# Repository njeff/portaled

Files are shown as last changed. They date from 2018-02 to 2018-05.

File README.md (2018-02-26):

# PortaLED

This is essentially a flashlight I designed because I wanted to use some free parts from TI. This uses the LM3410 driver to boost the voltage of the LiPo battery and drive the LEDs at a constant current. I have it setup to drive two 3W LEDs in series at approximately 630 mA (at max brightness). 

An ATTiny85 is used to control the whole system, and push button is used input.

This repository has the C firmware code and the KiCAD PCB design files. The PCB in the *const-led* folder has an additional battery gauge IC (MAX17043) for more accurate battery level tracking, and the one in *const-led-ez* doesn't. I only made the *ez* variant.

### Features
 - 8 brightness levels (maybe adjusted to be a linear/exponential ramp)
 - Battery level blink out (blinks out the volts, then tenth of a volt)
 - Low voltage/battery level cutoff
 - USB LiPo charging circuit

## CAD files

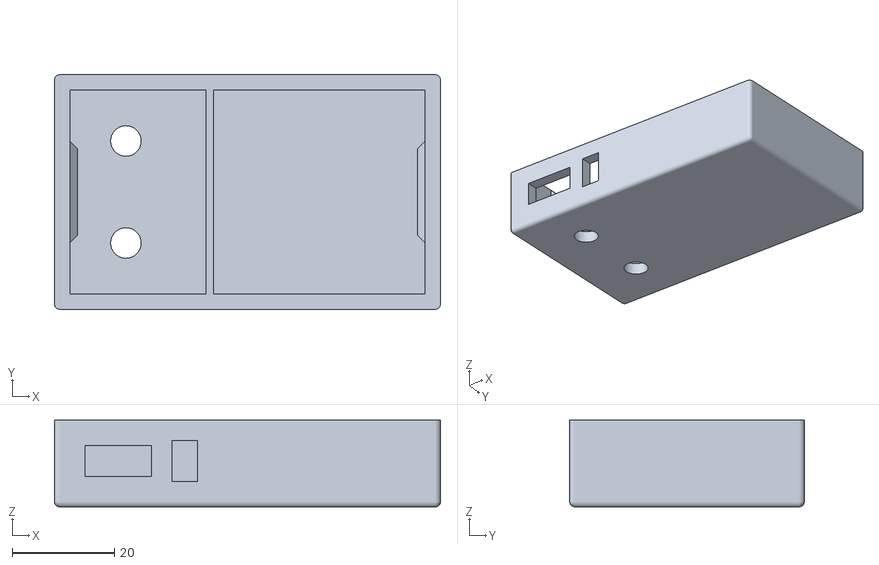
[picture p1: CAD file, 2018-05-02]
case/Case.stl
75.7 x 46.0 x 17.0

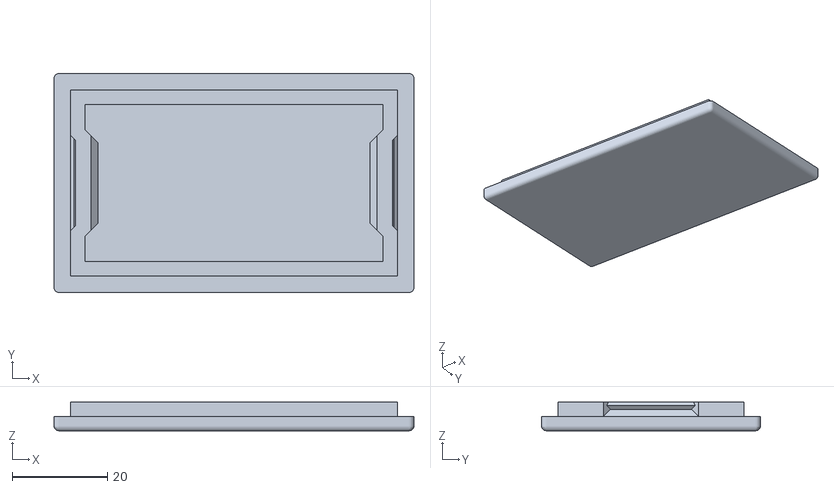
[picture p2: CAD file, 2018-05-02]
case/Cover.stl
75.7 x 46.0 x 6.00

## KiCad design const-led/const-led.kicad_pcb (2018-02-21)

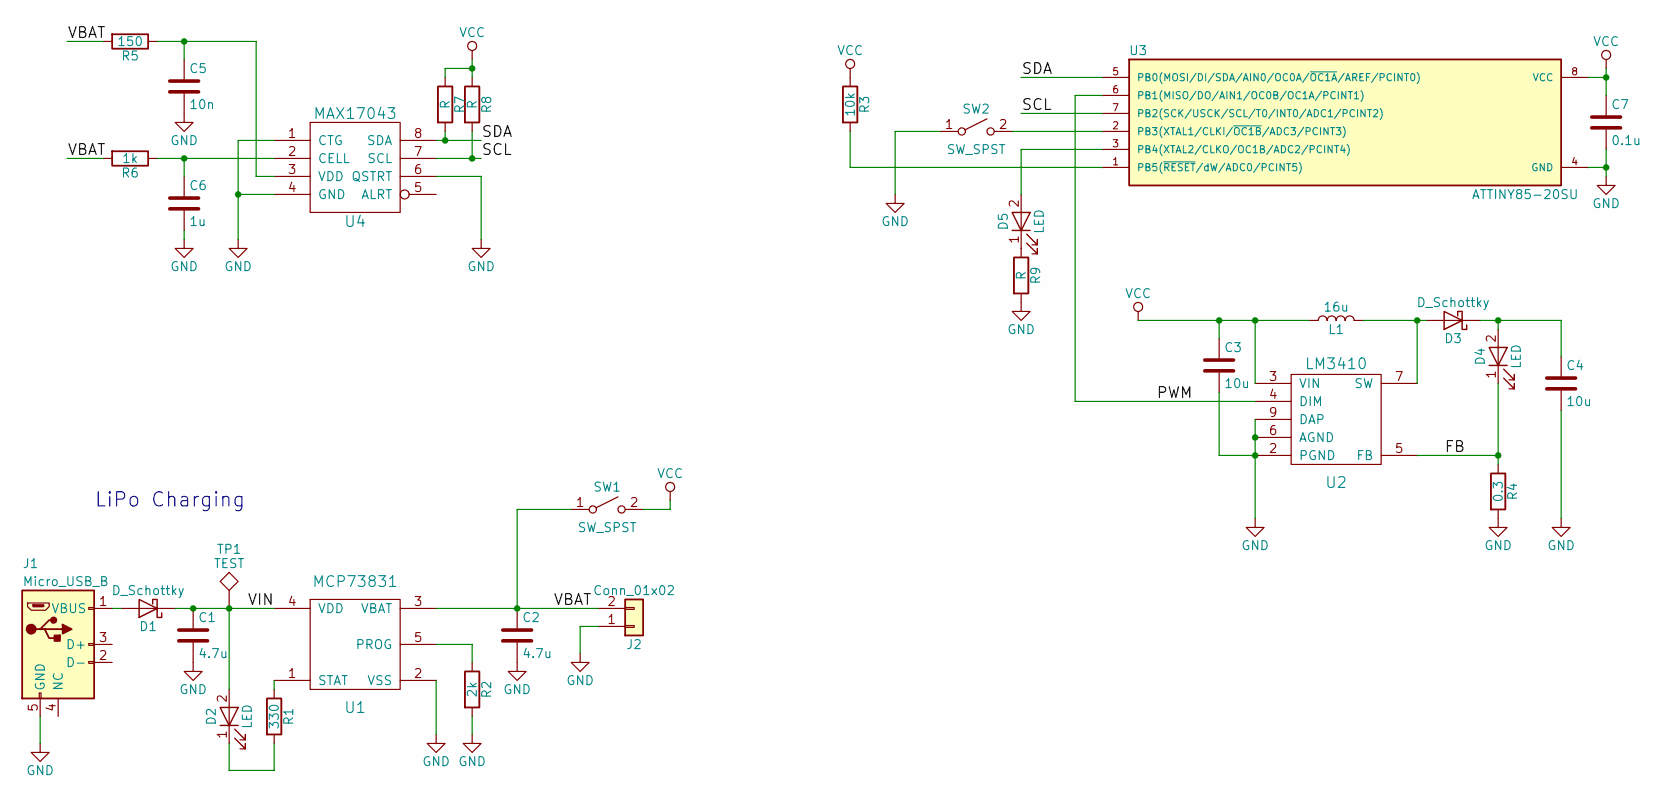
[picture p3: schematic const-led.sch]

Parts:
C1, C2: 4.7u; C_0603
C3, C4: 10u; C_1206
C5: 10n; C_0603
C6: 1u; C_0805
C7: 0.1u; C_0805
D1, D3: D_Schottky; D_SMA
D2, D5: LED; LED_0603
D4: LED; Pin_Header_Straight_1x02_Pitch2.54mm
J1: Micro_USB_B; Micro_USB_B_NH
J2: Conn_01x02; JST-PH-2
L1: 16u; muRata_L
R1: 330; R_0603
R2: 2k; R_0603
R3: 10k; R_0603
R4: 0.3; R_0805
R5: 150; R_0603
R6: 1k; R_0603
R7, R8, R9: R; R_0603
SW1, SW2: SW_SPST; Pin_Header_Straight_1x02_Pitch1.00mm
TP1: TEST; Measurement_Point_Round-SMD-Pad_Small
U1: MCP73831; SOT-23-5
U2: LM3410; MSOP-8-1EP_3x3mm_Pitch0.65mm
U3: ATTINY85-20SU; SOIC-8_8x5.25x1.27mm
U4: MAX17043; TDFN-8_2x3x0.75mm

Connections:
/FB: D4.1 (K), R4.1, U2.5 (FB)
/PWM: U2.4 (DIM), U3.6 (PB1(MISO/DO/AIN1/OC0B/OC1A/PCINT1))
/SCL: R8.2, U3.7 (PB2(SCK/USCK/SCL/T0/INT0/ADC1/PCINT2)), U4.7 (SCL)
/SDA: R7.2, U3.5 (PB0(MOSI/DI/SDA/AIN0/OC0A/~OC1A~/AREF/P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), U4.8 (SDA)
/VBAT: C2.1, J2.2, R5.2, R6.2, SW1.1 (A), U1.3 (VBAT)
/VIN: C1.1, D1.1 (K), D2.2 (A), TP1.1, U1.4 (VDD)
GND: C1.2, C2.2, C3.2, C4.2, C5.2, C6.2, C7.2, J1.5 (GND), J2.1, R2.2, R4.2, R9.2, SW2.1 (A), U1.2 (VSS), U2.2 (PGND), U2.6 (AGND), U2.9 (DAP), U3.4 (GND), U4.1 (CTG), U4.4 (GND), U4.6 (QSTRT)
unnamed: C4.1, D3.1 (K), D4.2 (A)
unnamed: C5.1, R5.1, U4.3 (VDD)
unnamed: C6.1, R6.1, U4.2 (CELL)
unnamed: D1.2 (A), J1.1 (VBUS)
unnamed: D2.1 (K), R1.2
unnamed: D3.2 (A), L1.2, U2.7 (SW)
unnamed: D5.1 (K), R9.1
unnamed: D5.2 (A), U3.3 (PB4(XTAL2/CLKO/OC1B/ADC2/PCINT4))
unnamed: R1.1, U1.1 (STAT)
unnamed: R2.1, U1.5 (PROG)
unnamed: R3.2, U3.1 (PB5(~RESET~/dW/ADC0/PCINT5))
unnamed: SW2.2 (B), U3.2 (PB3(XTAL1/CLKI/~OC1B~/ADC3/PCINT3))
VCC: C3.1, C7.1, L1.1, R3.1, R7.1, R8.1, SW1.2 (B), U2.3 (VIN), U3.8 (VCC)

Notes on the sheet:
LiPo Charging

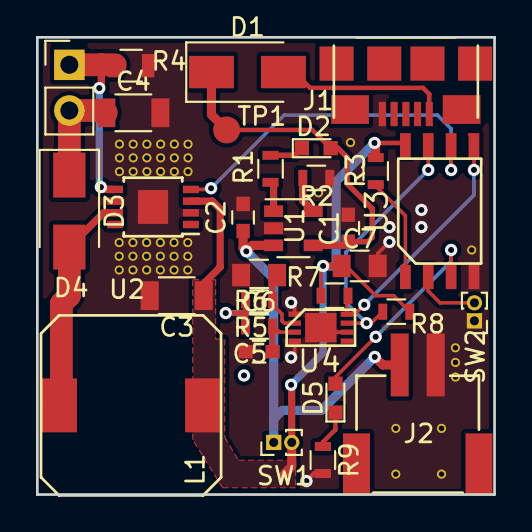
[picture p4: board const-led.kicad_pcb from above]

Board: 2 copper layers, 25.4 x 25.4 mm, 31 parts (0 on the bottom side), 20 nets.

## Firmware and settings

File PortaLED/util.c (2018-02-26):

#include "util.h"
#include "millis.h"

/************************************************************************/
/* Initialize all IO and timers
   PB1 - PWM 0C0B
   PB3 - Switch
   PB4 - Status LED                                                     */
/************************************************************************/
static unsigned long pressTime = 0;
static unsigned long releaseTime = 0;
static unsigned long lastTrigger = 0;
uint8_t h = 0;

void init() {
	DDRB = 1 << PB1 | 1 << PB4;
	PORTB = 0 << PB1 | 1 << PB3;
	
	// setup interrupt on push button
	MCUCR |= (1 << ISC00);
	GIMSK |= (1 << PCIE);
	PCMSK |= (1 << PCINT3);
	
	//setup millis
	init_millis();
	
	//setup PWM
	TCCR1 |= (1 << PWM1A) | (1 << CS10) | (1 << CS12) | (1 << COM1A1);
	OCR1C = 255;
	OCR1A = 0;
	
	init_adc();
	sei();
}

ISR(PCINT0_vect) {
	//prevent high speed triggering (debounce)
	if (millis() - lastTrigger > 15) {
		if (!(PINB & 1 << PB3)) {
			h = 1;
			pressTime = millis();
		} else {
			h = 0;
			releaseTime = millis();
		}
		lastTrigger = millis();
	}
}

uint8_t held() {
	return h;
}

unsigned long lastDuration() {
	if (pressTime < releaseTime) {
		return releaseTime - pressTime;
	}
	return 0;
}

// init ADC for VCC measurement
void init_adc() {
	//setup to measure internal 1.1V REF relative to battery voltage
	ADMUX |= (1 << MUX3) | (1 << MUX2);
	ADCSRA |= (1 << ADEN);
}

// returns VCC in millivolts
long readVoltage() {
	ADCSRA |= (1 << ADSC);
	while (ADCSRA & (1 << ADSC));
	
	uint16_t result = ADCL;
	result = (ADCH << 8) | result;
	return 1125300UL / result;
}

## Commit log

2018-02-21 Added millis and PWM
    [const-led.kicad_pcb, const-led.sch]
2018-02-25 Added (blocking) battery read out; still working on low PWM levels
2018-02-26 Changes now occur on button release
2018-05-02 Case parts
    [Case.stl, Cover.stl]
